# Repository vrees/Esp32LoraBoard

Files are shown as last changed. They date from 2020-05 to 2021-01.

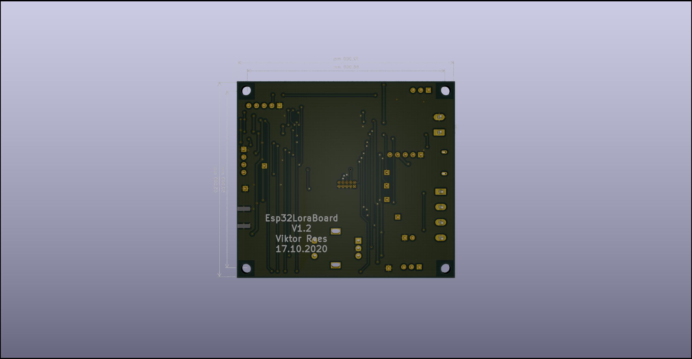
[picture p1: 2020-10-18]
kicad/images_V1.2/Esp32LoraBoard_Kicad_PCB_3D_back_V1.2.jpg

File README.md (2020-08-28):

# Esp32LoraBoard
ESP32 board including Lora RFM95 module optimized for low power deep sleep operation. 

## Features:
* works with single LiFePo battery
* external peripheral (i2c bus, Oled, measurement resistors) can be switxched off by FET transistors
* Open Source. Feel free to modify in KiCad and create your own boards
* I2C bus is decoubled be levelshifters
* optional power supply circuit (solder if you don't want do use LiFePo battery supply)
* optional Rotary Encoder 
* there is no UART chip (like CP2104) onboard in order to save power. Board can be programmed by using a simple external USB-to-UART converter (5 Pins: Ground, RX, TX RTS, DTR)

Esp32LoraBoard

PCB 3D

Schema

[PCB](../master/kicad/images_V1.1/Esp32LoraBoard_Kicad_PCB_V1.1.png)

### Power consumption

#### Power on and idle 

After PowerOn without sending any Lora data

| Mode | Current usage |
| --- |:---:|
| Normal operation  | 28 mA |

#### Deep Sleep 

Switched off all peripheral components and shutdown the RFM95W lora chip.

| Mode | Current usage |
| --- |:---:|
| Deep Sleep | 26 uA |

### Get Started

* Clone this project and open in platformio.

* Clone ttn-esp32 into lib subdir. Switch to branch dev to get it running. More info see https://github.com/manuelbl/ttn-esp32

* Following has to be changed under in ./lib/ttn-esp32 
Change following:

__src/lmic/config.h__
#define USE_ORIGINAL_AES

__src/aes/lmic_aes.c__
line 263:  u4_t t0, t1=0, t2, t3;

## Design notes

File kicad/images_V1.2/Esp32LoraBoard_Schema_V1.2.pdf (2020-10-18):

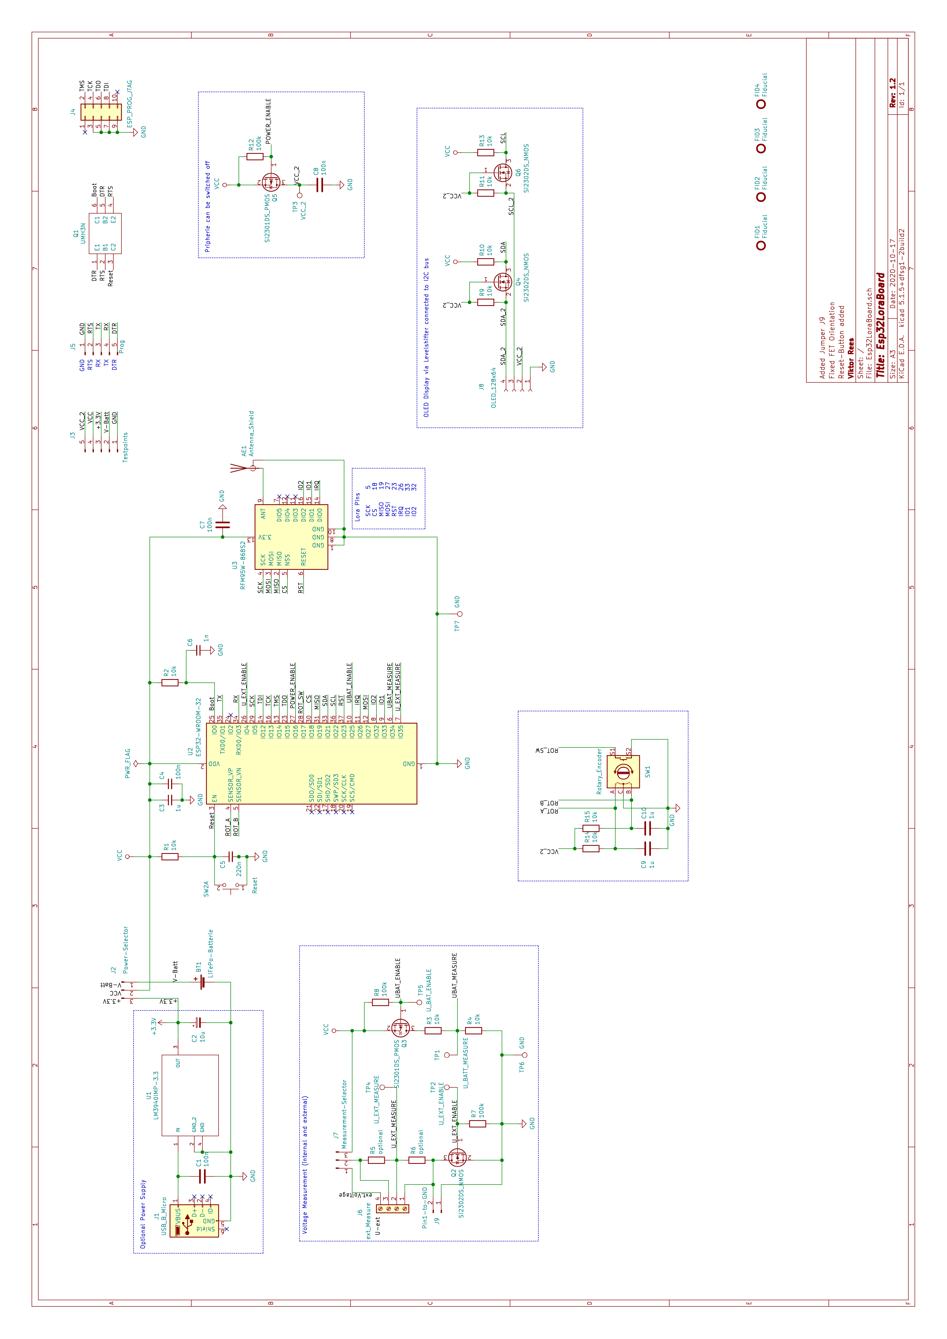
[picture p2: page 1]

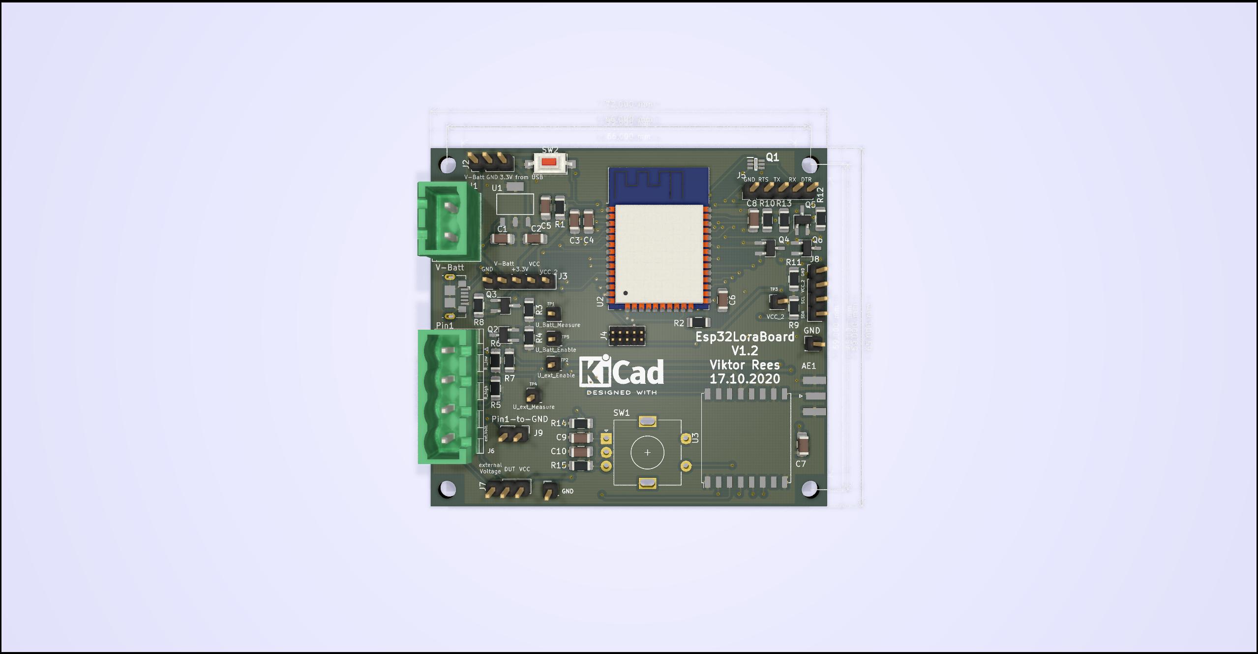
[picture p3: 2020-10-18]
kicad/images_V1.2/Esp32LoraBoard.jpg

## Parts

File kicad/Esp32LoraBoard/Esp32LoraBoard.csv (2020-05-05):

Source | /home/vrees/work/git-repos/water-level-meter-espidf/kicad/Esp32LoraBoard/Esp32LoraBoard.sch
Kicad Rev | Eeschema 5.1.4-e60b266~84~ubuntu18.04.1
Generated Date | Sa 18 Apr 2020 08:45:09 CEST
Title | Esp32LoraBoard
Company | Viktor Rees
Revision | 1.1
Date Issue | 2020-04-11
Comment | Reset-Button added
Reference | Value | Feld4 | Feld5 | Feld6 | Feld7 | Description | Height | Manufacturer_Name | Manufacturer_Part_Number | Library | Library Ref
U3 | RFM95W-868S2 | RF_Module | RFM95W-868S2
J1 | USB_B_Micro | Connector | USB_B_Micro
C1 | 100n | Device | C
C2 | 10u | Device | CP_Small
R1 | 10k | Device | R
C4 | 100n | Device | C_Small
C3 | 1u | Device | C_Small
AE1 | Antenna_Shield | Device | Antenna_Shield
BT1 | LiFePo-Batterie | Device | Battery_Cell
U1 | LM3940IMP-3.3 | 41K5122 | LM3940IMP-33 | SOT-223-4 | National Semiconductors |  |  |  |  | LM3940IMP-3.3 | LM3940IMP-3.3
J2 | Power-Selector | Connector | Conn_01x03_Male
J4 | ESP_PROG_JTAG | Connector_Generic | Conn_02x05_Odd_Even
C5 | 1n | Device | C_Small
R2 | 10k | Device | R
C6 | 1n | Device | C_Small
Q1 | UMH3N |  |  |  |  | 2 NPN pre-biased (Dual) 100mA 50V SC-70-6(SOT-363) Digital Transistors RoHS | 1.1 | Changjiang Electronics Tech (CJ) | UMH3N | UMH3N | UMH3N
J5 | Prog | Connector | Conn_01x05_Male
U2 | ESP32-WROOM-32 | RF_Module | ESP32-WROOM-32
Q2 | Si2302DS_NMOS | Device | Q_NMOS_GSD
R5 | optional | Device | R
R6 | optional | Device | R
R7 | 100k | Device | R
J7 | Measurement-Selector | Connector | Conn_01x03_Male
R8 | 100k | Device | R
TP1 | TP_U_BATT | Connector | TestPoint
R4 | 10k | Device | R
R3 | 10k | Device | R
J6 | ext_Measure | Connector | Screw_Terminal_01x04
J3 | Testpoints | Connector | Conn_01x05_Male
Q3 | Si2301DS_PMOS | Device | Q_PMOS_GSD
TP3 | VCC_2 | Connector | TestPoint
Q5 | Si2301DS_PMOS | Device | Q_PMOS_GSD
R12 | 100k | Device | R
R13 | 10k | Device | R
R11 | 10k | Device | R
Q6 | Si2302DS_NMOS | Device | Q_NMOS_GSD
J8 | OLED_128x64 | Connector | Conn_01x04_Female
R10 | 10k | Device | R
R9 | 10k | Device | R
Q4 | Si2302DS_NMOS | Device | Q_NMOS_GSD
TP2 | TP_U_EXT | Connector | TestPoint
C8 | 100n | Device | C
C7 | 100n | Device | C
SW1 | Rotary_Encoder | Device | Rotary_Encoder_Switch
R14 | 10k | Device | R
R15 | 10k | Device | R
C9 | 1u | Device | C
C10 | 1u | Device | C
SW2 | Reset | Switch | SW_Push_Dual_x2

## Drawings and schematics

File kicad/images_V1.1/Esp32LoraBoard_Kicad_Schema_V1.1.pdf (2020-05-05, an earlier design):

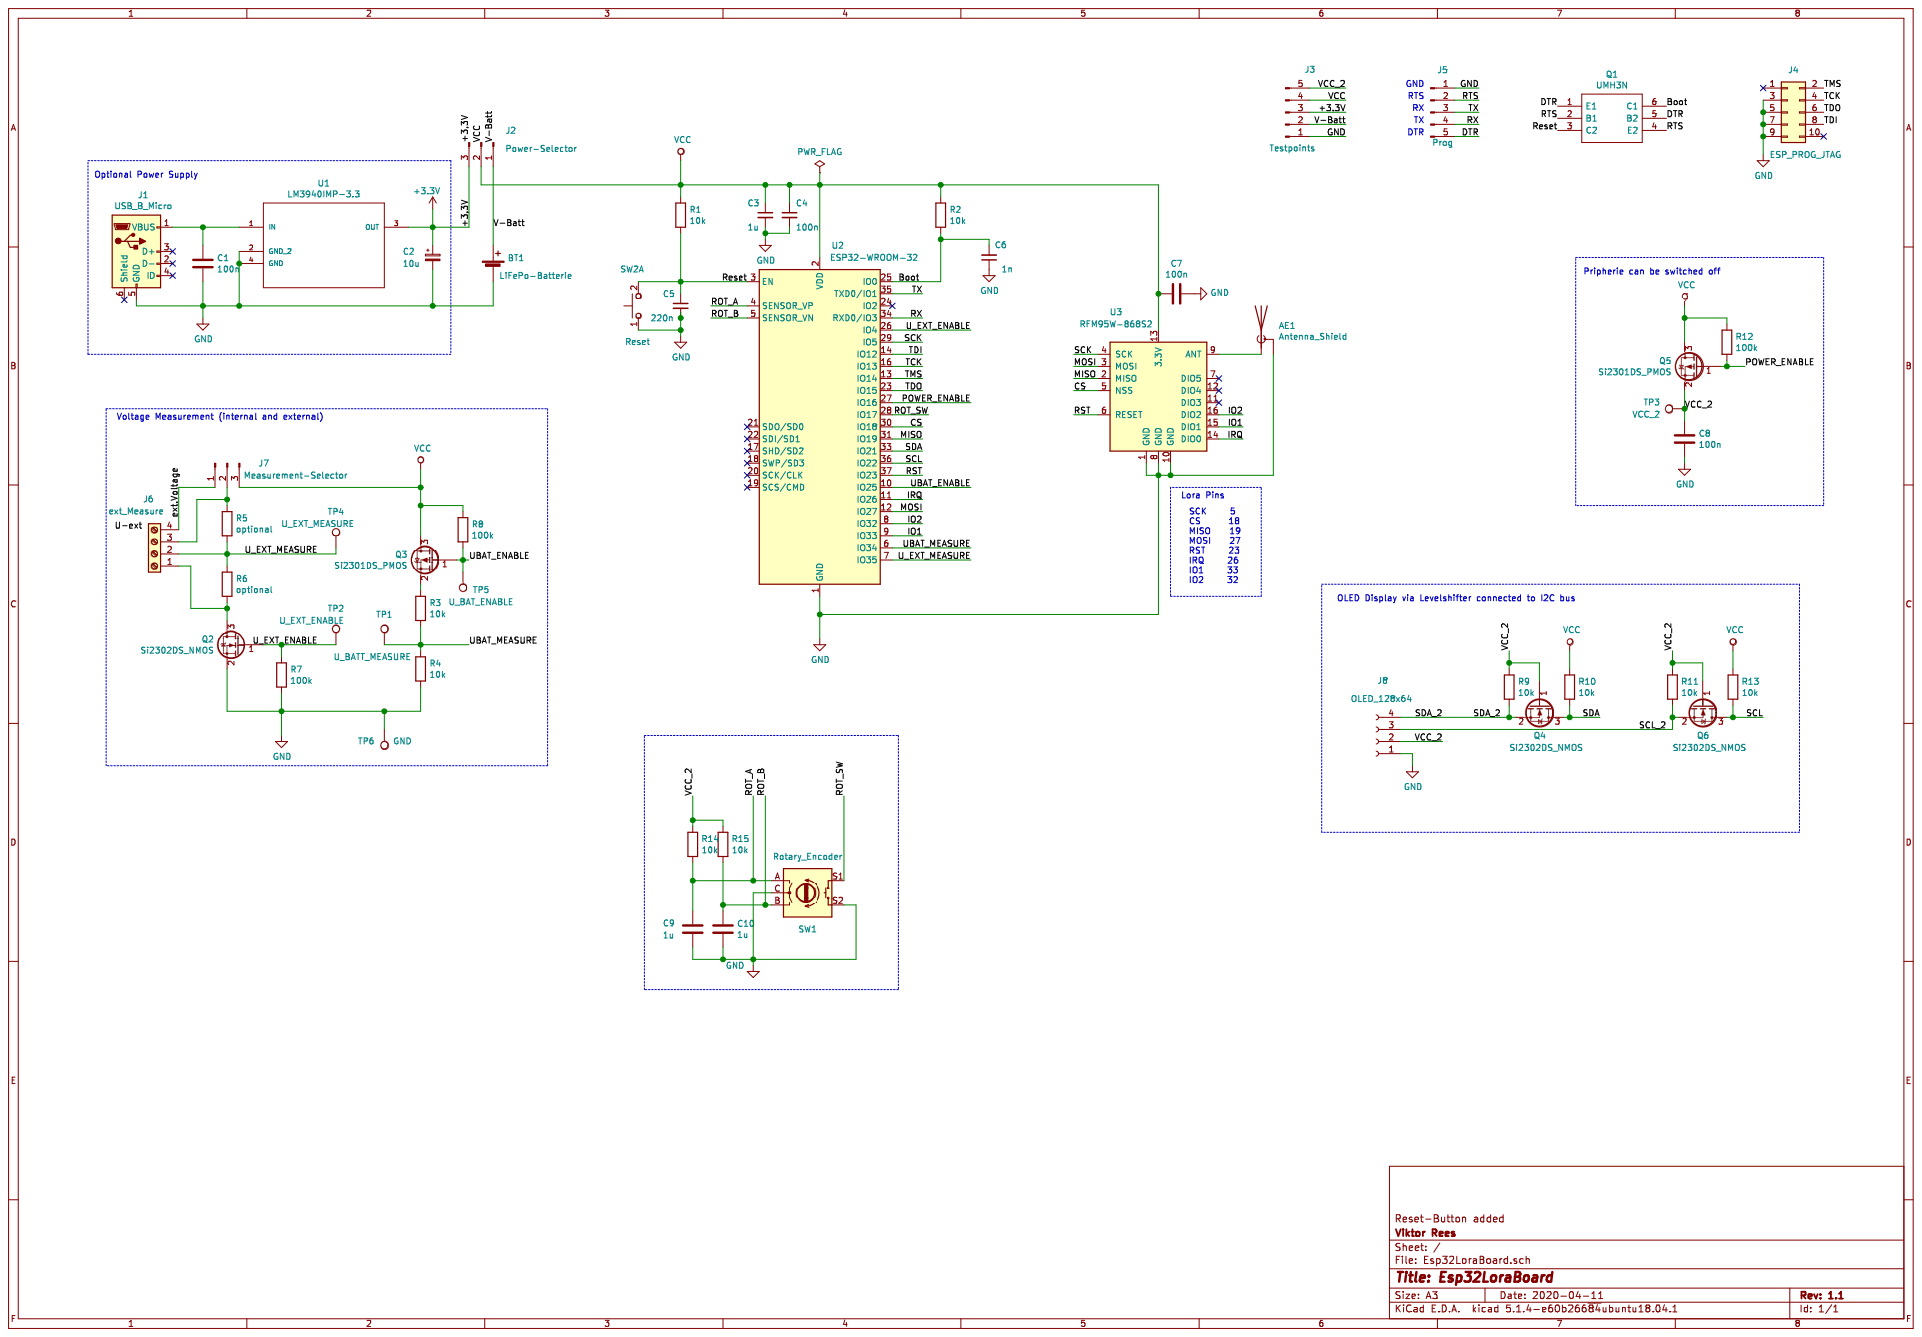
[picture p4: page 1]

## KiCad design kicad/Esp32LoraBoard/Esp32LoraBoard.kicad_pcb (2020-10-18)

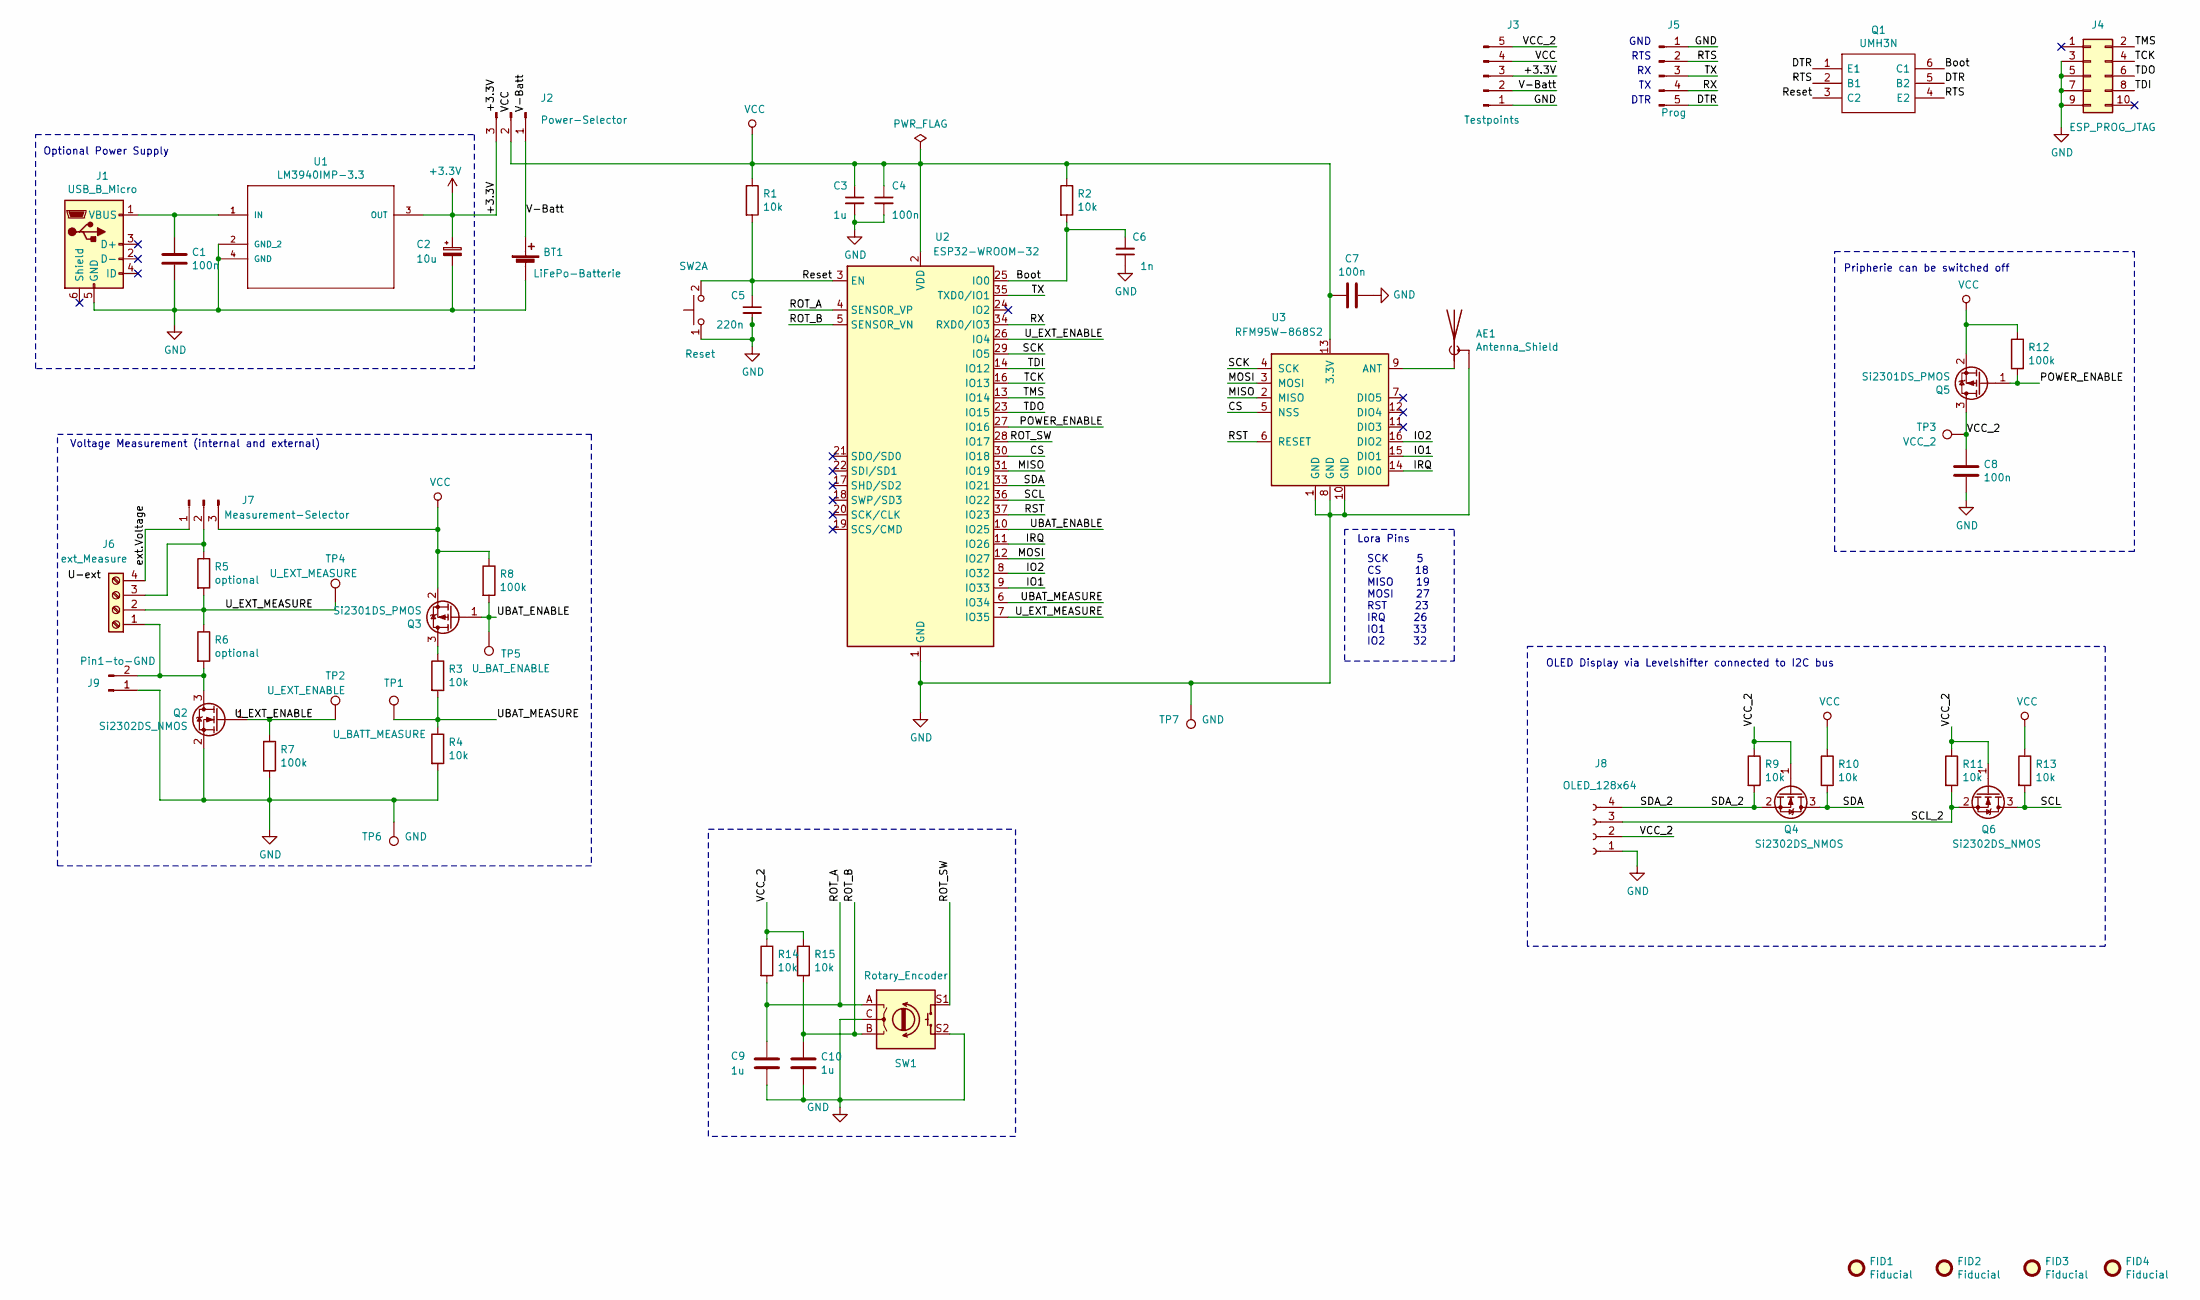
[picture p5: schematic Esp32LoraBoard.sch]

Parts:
AE1: Antenna_Shield; SMA_Samtec_SMA-J-P-H-ST-EM1_EdgeMount
BT1: LiFePo-Batterie; PhoenixContact_MSTBVA_2,5_2-G-5,08_1x02_P5.08mm_Vertical
C1, C4, C7, C8: 100n; C_1206_3216Metric_Pad1.42x1.75mm_HandSolder
C2: 10u; C_1206_3216Metric_Pad1.42x1.75mm_HandSolder
C3, C9, C10: 1u; C_1206_3216Metric_Pad1.42x1.75mm_HandSolder
C5: 220n; C_1206_3216Metric_Pad1.42x1.75mm_HandSolder
C6: 1n; C_1206_3216Metric_Pad1.42x1.75mm_HandSolder
FID1, FID2, FID3, FID4: Fiducial; Fiducial_0.75mm_Mask1.5mm
J1: USB_B_Micro; USB_Micro-B_GCT_USB3076-30-A
J2: Power-Selector; PinHeader_1x03_P2.54mm_Vertical
J3: Testpoints; PinHeader_1x05_P2.54mm_Vertical
J4: ESP_PROG_JTAG; PinHeader_2x05_P1.27mm_Vertical
J5: Prog; PinHeader_1x05_P2.54mm_Vertical
J6: ext_Measure; PhoenixContact_MSTBVA_2,5_4-G-5,08_1x04_P5.08mm_Vertical
J7: Measurement-Selector; PinHeader_1x03_P2.54mm_Vertical
J8: OLED_128x64; PinHeader_1x04_P2.54mm_Vertical
J9: Pin1-to-GND; PinHeader_1x02_P2.54mm_Vertical
Q1: UMH3N; SOT65P230X110-6N; Manufacturer_Part_Number UMH3N
Q2, Q4, Q6: Si2302DS_NMOS; TSOT-23_HandSoldering
Q3, Q5: Si2301DS_PMOS; TSOT-23_HandSoldering
R1, R2, R3, R4, R9, R10, R11, R13, R14, R15: 10k; R_1206_3216Metric_Pad1.42x1.75mm_HandSolder
R5, R6: optional; R_1206_3216Metric_Pad1.42x1.75mm_HandSolder
R7, R8, R12: 100k; R_1206_3216Metric_Pad1.42x1.75mm_HandSolder
SW1: Rotary_Encoder; RotaryEncoder_Alps_EC11E-Switch_Vertical_H20mm
SW2: Reset; SW_SPST_CK_RS282G05A3
TP1: U_BATT_MEASURE; PinHeader_1x01_P2.54mm_Vertical
TP2: U_EXT_ENABLE; PinHeader_1x01_P2.54mm_Vertical
TP3: VCC_2; PinHeader_1x01_P2.54mm_Vertical
TP4: U_EXT_MEASURE; PinHeader_1x01_P2.54mm_Vertical
TP5: U_BAT_ENABLE; PinHeader_1x01_P2.54mm_Vertical
TP6, TP7: GND; PinHeader_1x01_P2.54mm_Vertical
U1: LM3940IMP-3.3; SOT230P696X180-4N
U2: ESP32-WROOM-32
U3: RFM95W-868S2; HOPERF_RFM9XW_SMD

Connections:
+3V3: C2.1, J2.3, J3.3, U1.3 (OUT)
/Boot: C6.2, Q1.6 (C1), R2.2, U2.25 (IO0)
/CS: U2.30 (IO18), U3.5 (NSS)
/DTR: J5.5, Q1.1 (E1), Q1.5 (B2)
/IO1: U2.9 (IO33), U3.15 (DIO1)
/IO2: U2.8 (IO32), U3.16 (DIO2)
/IRQ: U2.11 (IO26), U3.14 (DIO0)
/MISO: U2.31 (IO19), U3.2 (MISO)
/MOSI: U2.12 (IO27), U3.3 (MOSI)
/POWER_ENABLE: Q5.1 (G), R12.2, U2.27 (IO16)
/ROT_A: C9.1, R14.2, SW1.A, U2.4 (SENSOR_VP)
/ROT_B: C10.1, R15.2, SW1.B, U2.5 (SENSOR_VN)
/ROT_SW: SW1.S1, U2.28 (IO17)
/RST: U2.37 (IO23), U3.6 (RESET)
/RTS: J5.2, Q1.2 (B1), Q1.4 (E2)
/RX: J5.4, U2.34 (RXD0/IO3)
/Reset: C5.1, Q1.3 (C2), R1.2, SW2.2 (D), U2.3 (EN)
/SCK: U2.29 (IO5), U3.4 (SCK)
/SCL: Q6.3 (D), R13.2, U2.36 (IO22)
/SCL_2: J8.3, Q6.2 (S), R11.2
/SDA: Q4.3 (D), R10.2, U2.33 (IO21)
/SDA_2: J8.4, Q4.2 (S), R9.2
/TCK: J4.4, U2.16 (IO13)
/TDI: J4.8, U2.14 (IO12)
/TDO: J4.6, U2.23 (IO15)
/TMS: J4.2, U2.13 (IO14)
/TX: J5.3, U2.35 (TXD0/IO1)
/UBAT_ENABLE: Q3.1 (G), R8.2, TP5.1, U2.10 (IO25)
/UBAT_MEASURE: R3.2, R4.1, TP1.1, U2.6 (IO34)
/U_EXT_ENABLE: Q2.1 (G), R7.1, TP2.1, U2.26 (IO4)
/U_EXT_MEASURE: J6.2, R5.2, R6.1, TP4.1, U2.7 (IO35)
/V-Batt: BT1.1 (+), J2.1, J3.2
/VCC_2: C8.1, J3.5, J8.2, Q4.1 (G), Q5.3 (D), Q6.1 (G), R9.1, R11.1, R14.1, R15.1, TP3.1
/ext.Voltage: J6.4, J7.1
GND: AE1.2 (Shield), BT1.2 (-), C1.2, C2.2, C3.2, C4.2, C5.2, C6.1, C7.1, C8.2, C9.2, C10.2, J1.5 (GND), J3.1, J4.3, J4.5, J4.7, J4.9, J5.1, J8.1, J9.1, Q2.2 (S), R4.2, R7.2, SW1.C, SW1.S2, SW2.1 (C), TP6.1, TP7.1, U1.2 (GND_2), U1.4 (GND), U2.1 (GND), U2.15 (GND), U2.38 (GND), U2.39 (GND), U3.1 (GND), U3.8 (GND), U3.10 (GND)
unnamed: AE1.1 (A), U3.9 (ANT)
unnamed: C1.1, J1.1 (VBUS), U1.1 (IN)
unnamed: J6.1, J9.2, Q2.3 (D), R6.2
unnamed: J6.3, J7.2, R5.1
unnamed: Q3.3 (D), R3.1
VCC: C3.1, C4.1, C7.2, J2.2, J3.4, J7.3, Q3.2 (S), Q5.2 (S), R1.1, R2.1, R8.1, R10.1, R12.1, R13.1, U2.2 (VDD), U3.13 (3.3V)

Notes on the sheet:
SCK 5 CS 18 MISO 19 MOSI 27 RST 23 IRQ 26 IO1 33 IO2 32
DTR
RTS
GND
Lora Pins
OLED Display via Levelshifter connected to I2C bus
Pripherie can be switched off
Voltage Measurement (internal and external)
Optional Power Supply

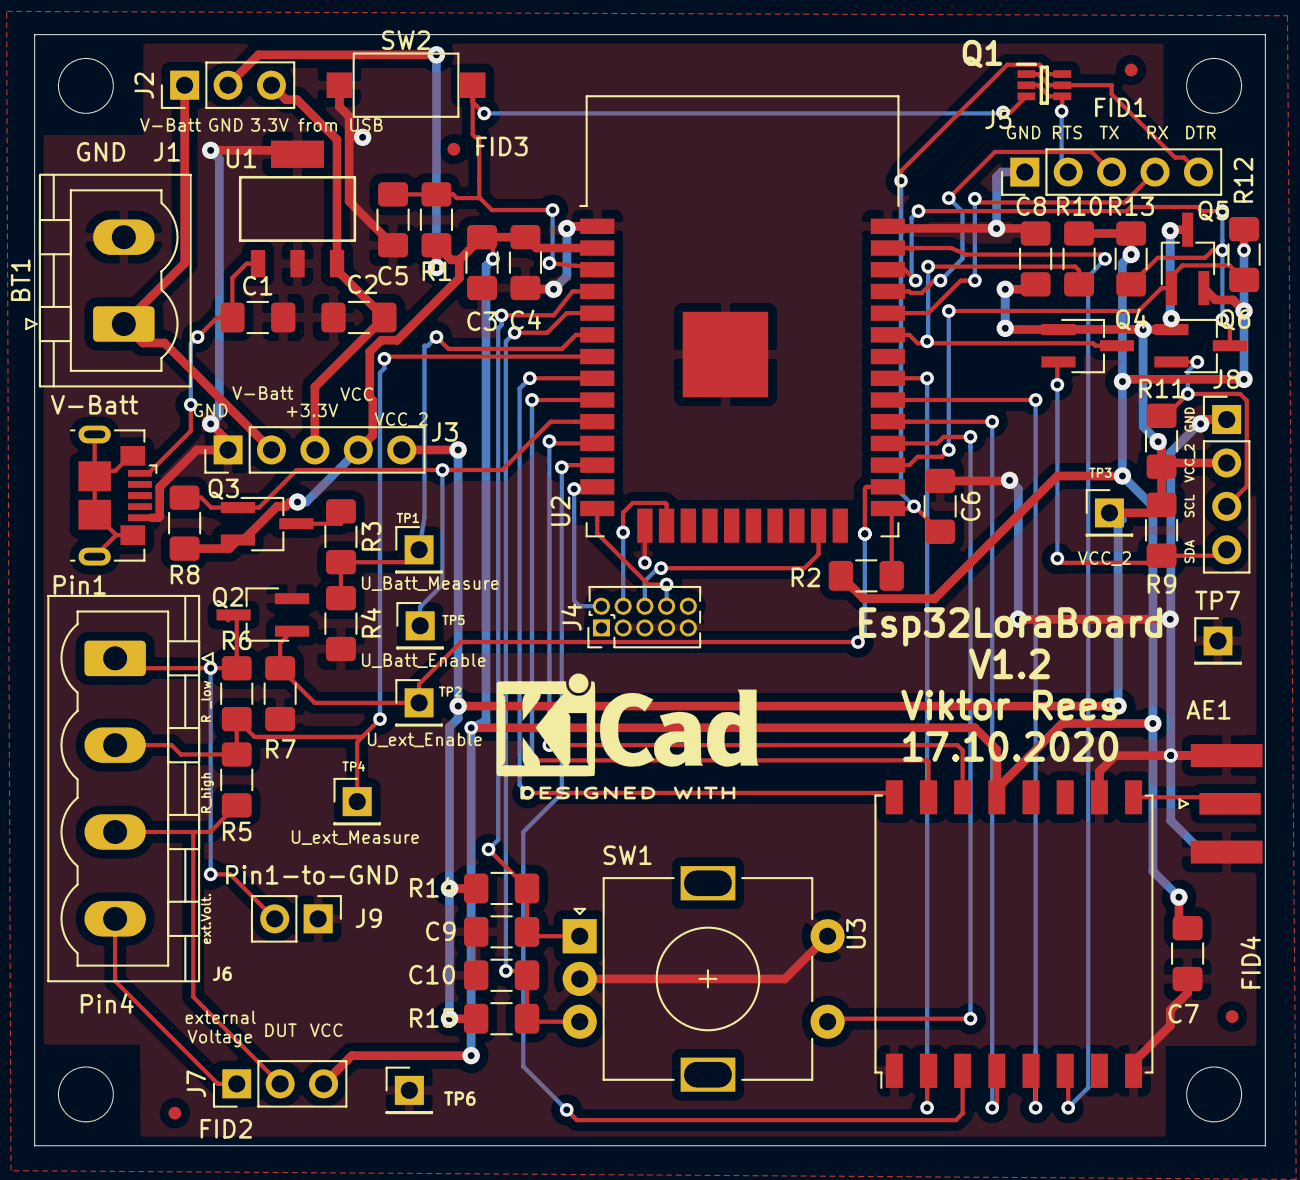
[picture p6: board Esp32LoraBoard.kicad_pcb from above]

Board: 2 copper layers, 72.0 x 65.0 mm, 58 parts (0 on the bottom side), 41 nets.

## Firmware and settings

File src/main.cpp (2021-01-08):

#include "freertos/FreeRTOS.h"
#include "driver/gpio.h"
#include <driver/spi_master.h>
#include <freertos/task.h>
#include <stdio.h>
#include <string.h>
#include "esp_event.h"
#include "esp_log.h"
#include "nvs_flash.h"
#include "esp_sleep.h"
#include "TheThingsNetwork.h"

#include "esp32-lora-board-pins.h"
#include "sleep-wakeup.h"
#include "voltage.h"

// #include "sdkconfig.h"

#include "display.h"

extern uint8_t payload[];

static TheThingsNetwork ttn;

// TTN-App: public-dummy

// debug board zum Testen
// MAC: 3C:71:BF:4C:FC:18
const char *appEui = "70B3D57ED002FB99";
const char *appKey = "E2A4A1D6D67ADD8D539D13DC985F369E";

const unsigned TX_INTERVAL = 5;

void initEsp32Resources()
{
    esp_err_t err;
    // Initialize the GPIO ISR handler service
    err = gpio_install_isr_service(ESP_INTR_FLAG_IRAM);
    ESP_ERROR_CHECK(err);

    // Initialize the NVS (non-volatile storage) for saving and restoring the keys
    err = nvs_flash_init();
    ESP_ERROR_CHECK(err);

    // Initialize SPI bus
    spi_bus_config_t spi_bus_config;
    spi_bus_config.miso_io_num = TTN_PIN_SPI_MISO;
    spi_bus_config.mosi_io_num = TTN_PIN_SPI_MOSI;
    spi_bus_config.sclk_io_num = TTN_PIN_SPI_SCLK;
    spi_bus_config.quadwp_io_num = -1;
    spi_bus_config.quadhd_io_num = -1;
    spi_bus_config.max_transfer_sz = 0;
    err = spi_bus_initialize(TTN_SPI_HOST, &spi_bus_config, TTN_SPI_DMA_CHAN);
    ESP_ERROR_CHECK(err);
}

void printRFSettings(const char *window, const TTNRFSettings &settings)
{
    int bw = (1 << (static_cast<int>(settings.bandwidth) - 1)) * 125;
    int sf = static_cast<int>(settings.spreadingFactor) + 5;

    if (settings.spreadingFactor == kTTNSFNone)
    {
        printf("%s: not used\n", window);
    }
    else if (settings.spreadingFactor == kTTNFSK)
    {
        printf("%s: FSK, BW %dkHz, %d.%d MHz\n",
               window, bw, settings.frequency / 1000000, (settings.frequency % 1000000 + 50000) / 100000);
    }
    else
    {
        printf("%s: SF%d, BW %dkHz, %d.%d MHz\n",
               window, sf, bw, settings.frequency / 1000000, (settings.frequency % 1000000 + 50000) / 100000);
    }
}

void printAllRFSettings()
{
    printRFSettings("TX ", ttn.txSettings());
    printRFSettings("RX1", ttn.rx1Settings());
    printRFSettings("RX2", ttn.rx2Settings());
    printf("RSSI: %d dBm\n", ttn.rssi());
}

void sendMessages(void *pvParameter)
{
    TTNResponseCode res = ttn.transmitMessage(payload, PAYLOAD_LENGTH);
    printf(res == kTTNSuccessfulTransmission ? "Message sent.\n" : "Transmission failed.\n");

    printAllRFSettings();

    vTaskDelay(TX_INTERVAL * 200 / portTICK_PERIOD_MS);

    ttn.shutdown();
    powerOffAndSleep();
}

void messageReceived(const uint8_t *message, size_t length, port_t port)
{
    printf("*********************************************\n");
    printf("Message of %d bytes received on port %d:", length, port);
    for (int i = 0; i < length; i++)
        printf(" %02x", message[i]);
    printf("\n");
    printf("*********************************************\n");
}

void showMacAddress()
{
    uint8_t mac[6];
    esp_err_t err = esp_efuse_mac_get_default(mac);
    ESP_ERROR_CHECK(err);
    printf("MAC-Adress:   ");
    for (int i = 0; i < 6; i++)
        printf(" %02x", mac[i]);
    printf("\n");
}

extern "C" void app_main(void)
{
    printf("Start app on ESP32LoraBoard\n");
    // vTaskDelay(1000 / portTICK_PERIOD_MS); //Take some time to open up the Serial Monitor

    wakeupAndInit();

    initEsp32Resources();

    initSSD1306i2c(NULL);

    // Configure the SX127x pins
    ttn.configurePins(TTN_SPI_HOST, TTN_PIN_NSS, TTN_PIN_RXTX, TTN_PIN_RST, TTN_PIN_DIO0, TTN_PIN_DIO1);

    readSensorValues();
    displayData();

    showMacAddress();
    ttn.provisionWithMAC(appEui, appKey);
    // ttn.setAdrEnabled(false);
    
    // Register callback for received messages
    ttn.onMessage(messageReceived);


    printf("Joining...\n");
    if (ttn.join())
    {
        printf("Joined.\n");
        xTaskCreate(sendMessages, "send_messages", 1024 * 4, (void *)0, 3, nullptr);
    }
    else
    {
        printf("Join failed. Goodbye\n");
    }
}

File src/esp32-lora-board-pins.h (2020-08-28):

#ifndef _ESP32_LORA_BOARD_PINS_H_
#define _ESP32_LORA_BOARD_PINS_H_

// Pins for LORA chip SPI interface, reset line and interrupt lines (compatible TTGO LoRa32 V2.1.6)
// #define LORA_SCK  (5) 
// #define LORA_CS   (18)
// #define LORA_MISO (19)
// #define LORA_MOSI (27)
// #define LORA_RST  (23)
// #define LORA_IRQ  (26)
// #define LORA_IO1  (33)
// #define LORA_IO2  (32)

// Pins and other resources
#define TTN_SPI_HOST      HSPI_HOST
#define TTN_SPI_DMA_CHAN  1
#define TTN_PIN_SPI_SCLK  5
#define TTN_PIN_SPI_MOSI  27
#define TTN_PIN_SPI_MISO  19
#define TTN_PIN_NSS       18
#define TTN_PIN_RXTX      TTN_NOT_CONNECTED
#define TTN_PIN_RST       23
#define TTN_PIN_DIO0      26
#define TTN_PIN_DIO1      33


// JTAG ESP-Programmer
#define JTAG_TDI        (12)
#define JTAG_TCK        (13)
#define JTAG_TMS        (14)
#define JTAG_TDO        (15)

// Control Pins
#define POWER_ENABLE    (16)
#define U_EXT_ENABLE    (4)
#define U_EXT_MEASURE   (35)    // ADC1_CHANNEL_7
#define U_BAT_ENABLE     (25)
#define U_BAT_MEASURE    (34)   // ADC1_CHANNEL_6

// IO
#define ROTARY_SWITCH   (17)
#define ROTARY_A        (36)
#define ROTARY_B        (39)
#define RESERVED        (2)

// I2C Bus
#define I2C_SDA         (21)
#define I2C_SCL         (22)

// Serial Connection
#define TXDO            (1)
#define RXDO            (3)

#endif

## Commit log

2020-05-05 added kicad files
    [Esp32LoraBoard-B_Cu.gbr, Esp32LoraBoard-B_Mask.gbr, Esp32LoraBoard-B_Paste.gbr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]
2020-05-26 Power FETs disabled during startup
2020-05-28 try to integrate ttn-esp32
2020-05-29 fix ttn-esp32 problems
2020-08-28 added voltage measurment
2020-08-28 updated ttn-esp32
2020-10-18 new PCB Version V1.2
    [Esp32LoraBoard-B_Cu.gbr, Esp32LoraBoard-B_Mask.gbr, Esp32LoraBoard-B_Paste.gbr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]
2021-01-08 Antennen Messungen hinzugefügt
    [Messungen-Antennen.ods]
